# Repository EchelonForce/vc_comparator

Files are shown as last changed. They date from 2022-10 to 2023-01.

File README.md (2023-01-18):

# Eurorack Comparator Module

This is a design for a eurorack comparator module using an LM393.

Full writeup here: https://www.robotdialogs.com/2023/01/eurorack-comparator-module.html

This work is licensed under a Creative Commons Attribution-NonCommercial-ShareAlike 4.0 International License. https://creativecommons.org/licenses/by-nc-sa/4.0/

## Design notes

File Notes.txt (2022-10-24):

https://tinyurl.com/2jhrsgzh
https://tinyurl.com/2guo99mw- updated with output level adjust trim pots
https://tinyurl.com/2kqce7o7 with caps and input filter

Made on bread board, had a few noisy areas but adding caps helped. Also put a rc filter on the signal input in the schematic just in case.

Issues on v1 PCB:
 - Negative of the LM393 should be to GND like on the breadboard... cut the trace to -12V and short C8 to GND with a 0 Ohm.

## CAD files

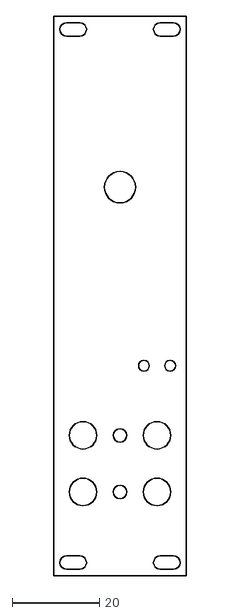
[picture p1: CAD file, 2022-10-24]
front_panel_v1/vc_comparator_v1_front_panel_v1_no_engraving.dxf
30.5 x 128.5

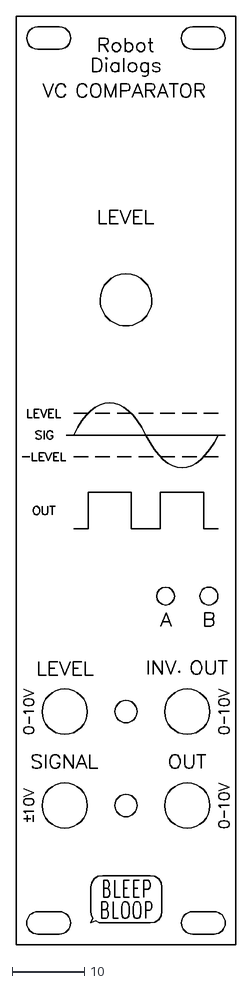
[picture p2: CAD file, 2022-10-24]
front_panel_v1/vc_comparator_v1_front_panel_v1_engraving.dxf
30.4 x 128.4

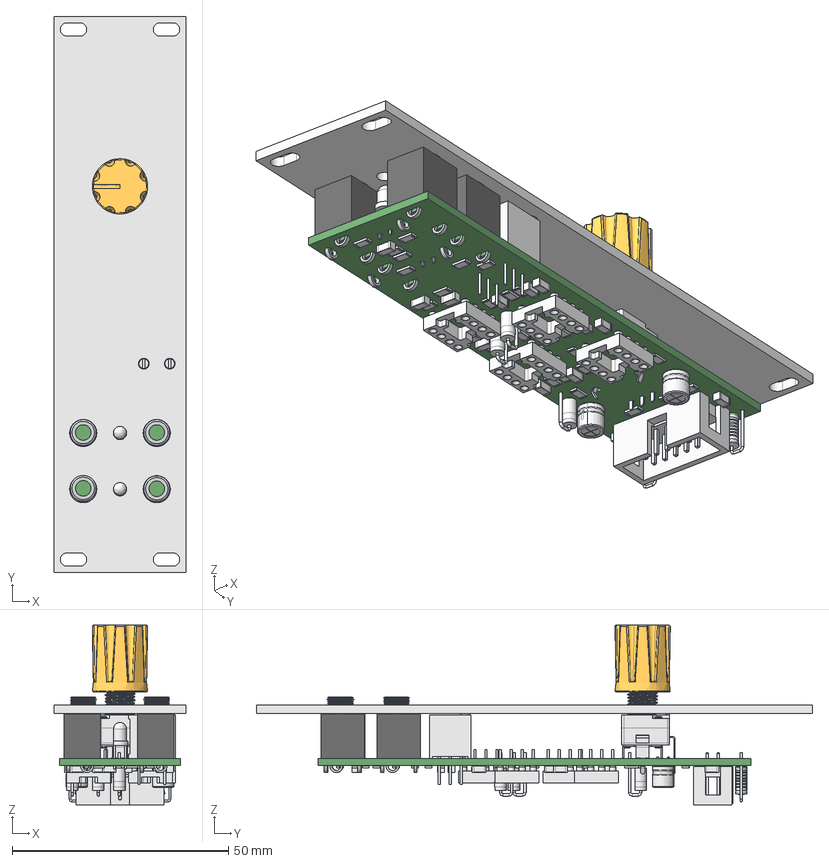
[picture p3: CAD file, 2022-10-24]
front_panel_v1/vc_comparator_v1_front_panel_v1.FCStd
30.5 x 128.5 x 41.6 mm
vc_comparator_v1 PCB

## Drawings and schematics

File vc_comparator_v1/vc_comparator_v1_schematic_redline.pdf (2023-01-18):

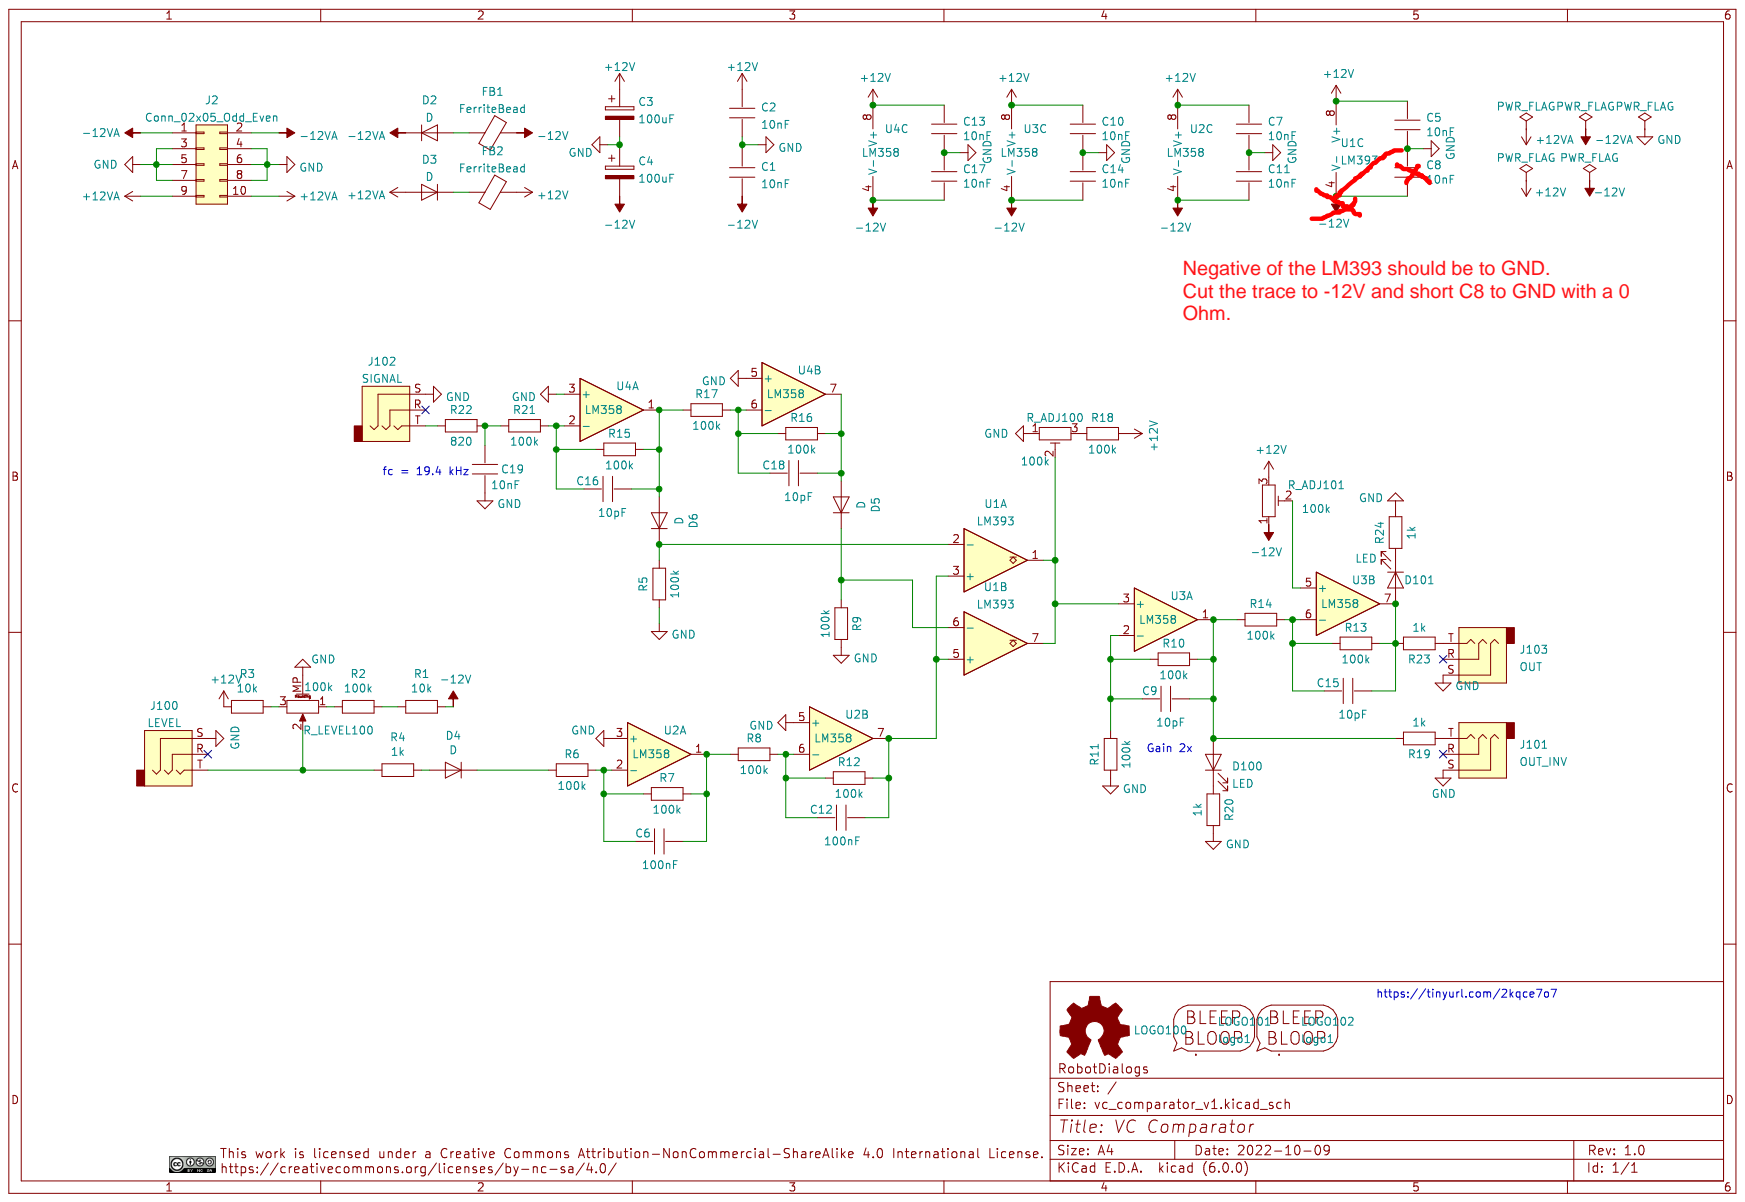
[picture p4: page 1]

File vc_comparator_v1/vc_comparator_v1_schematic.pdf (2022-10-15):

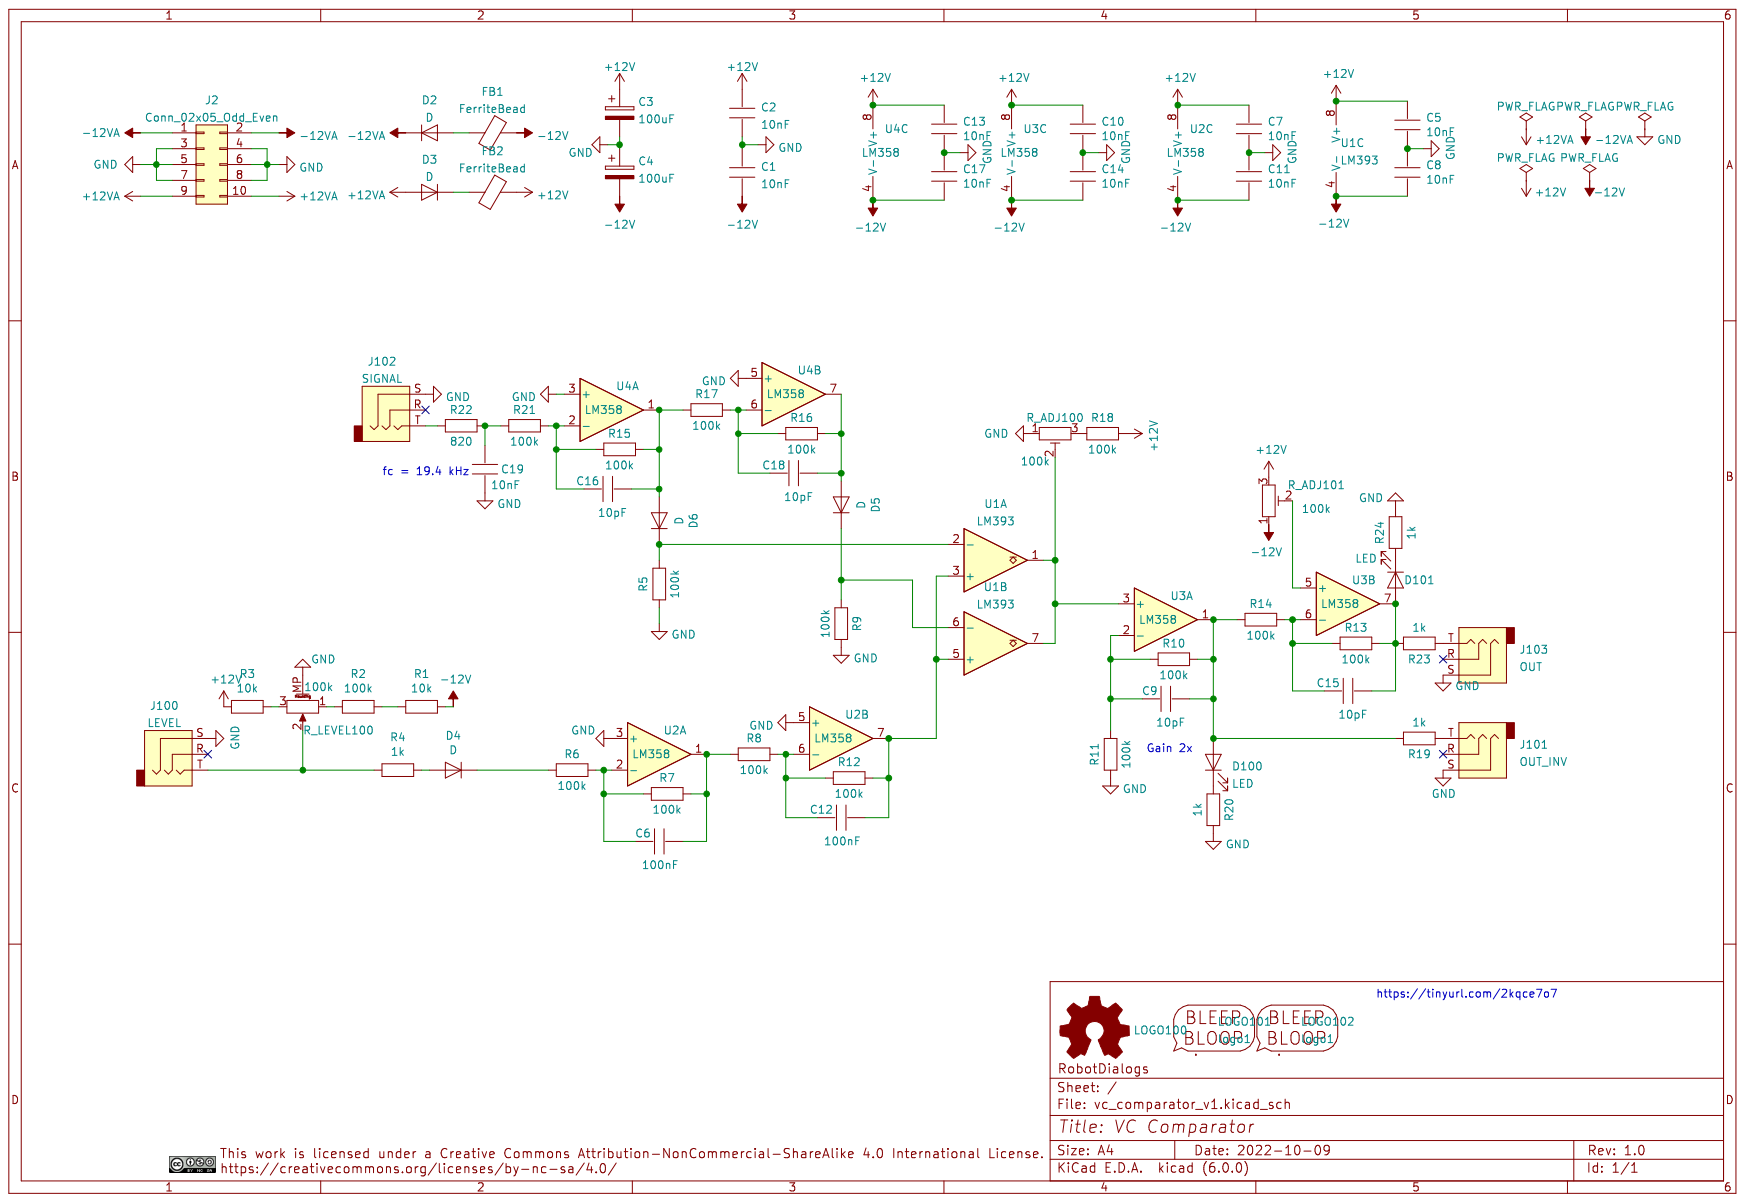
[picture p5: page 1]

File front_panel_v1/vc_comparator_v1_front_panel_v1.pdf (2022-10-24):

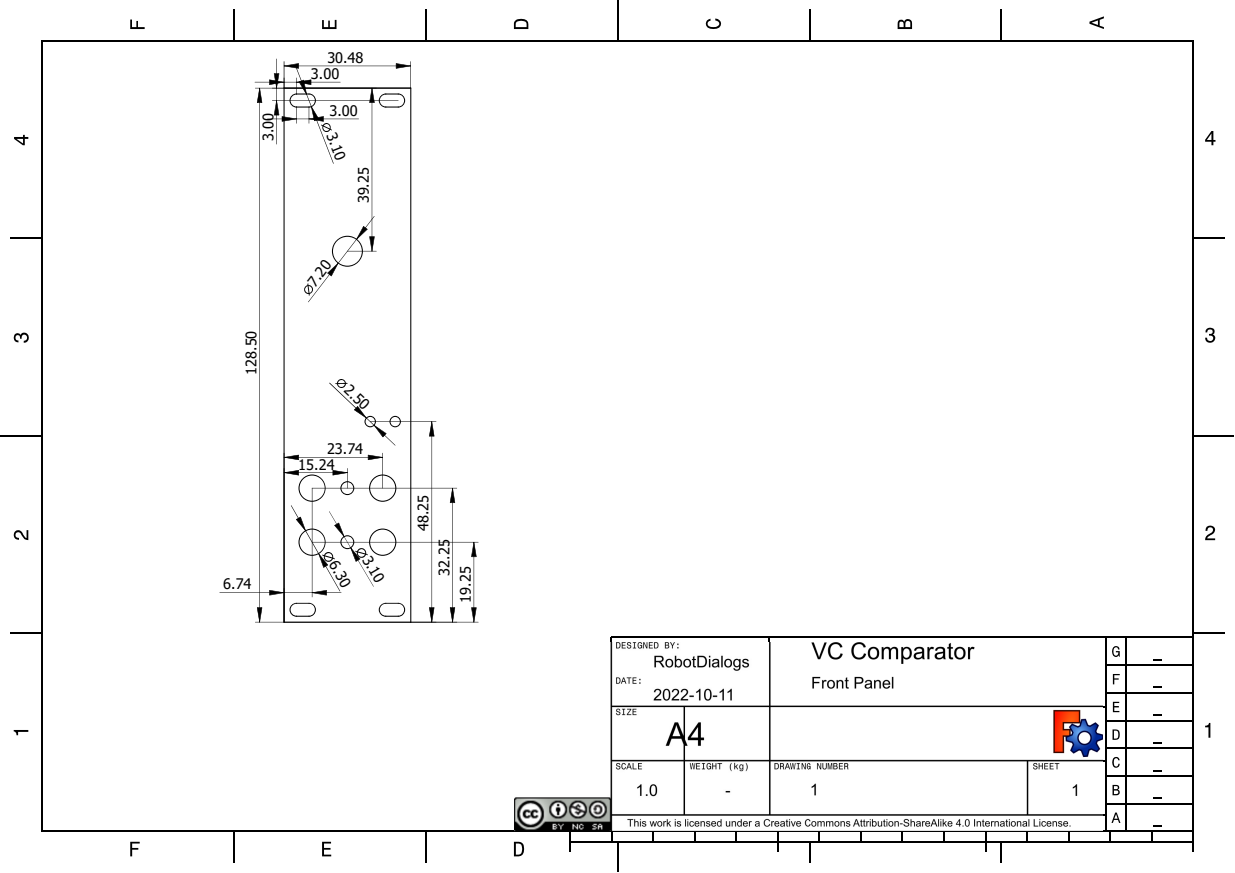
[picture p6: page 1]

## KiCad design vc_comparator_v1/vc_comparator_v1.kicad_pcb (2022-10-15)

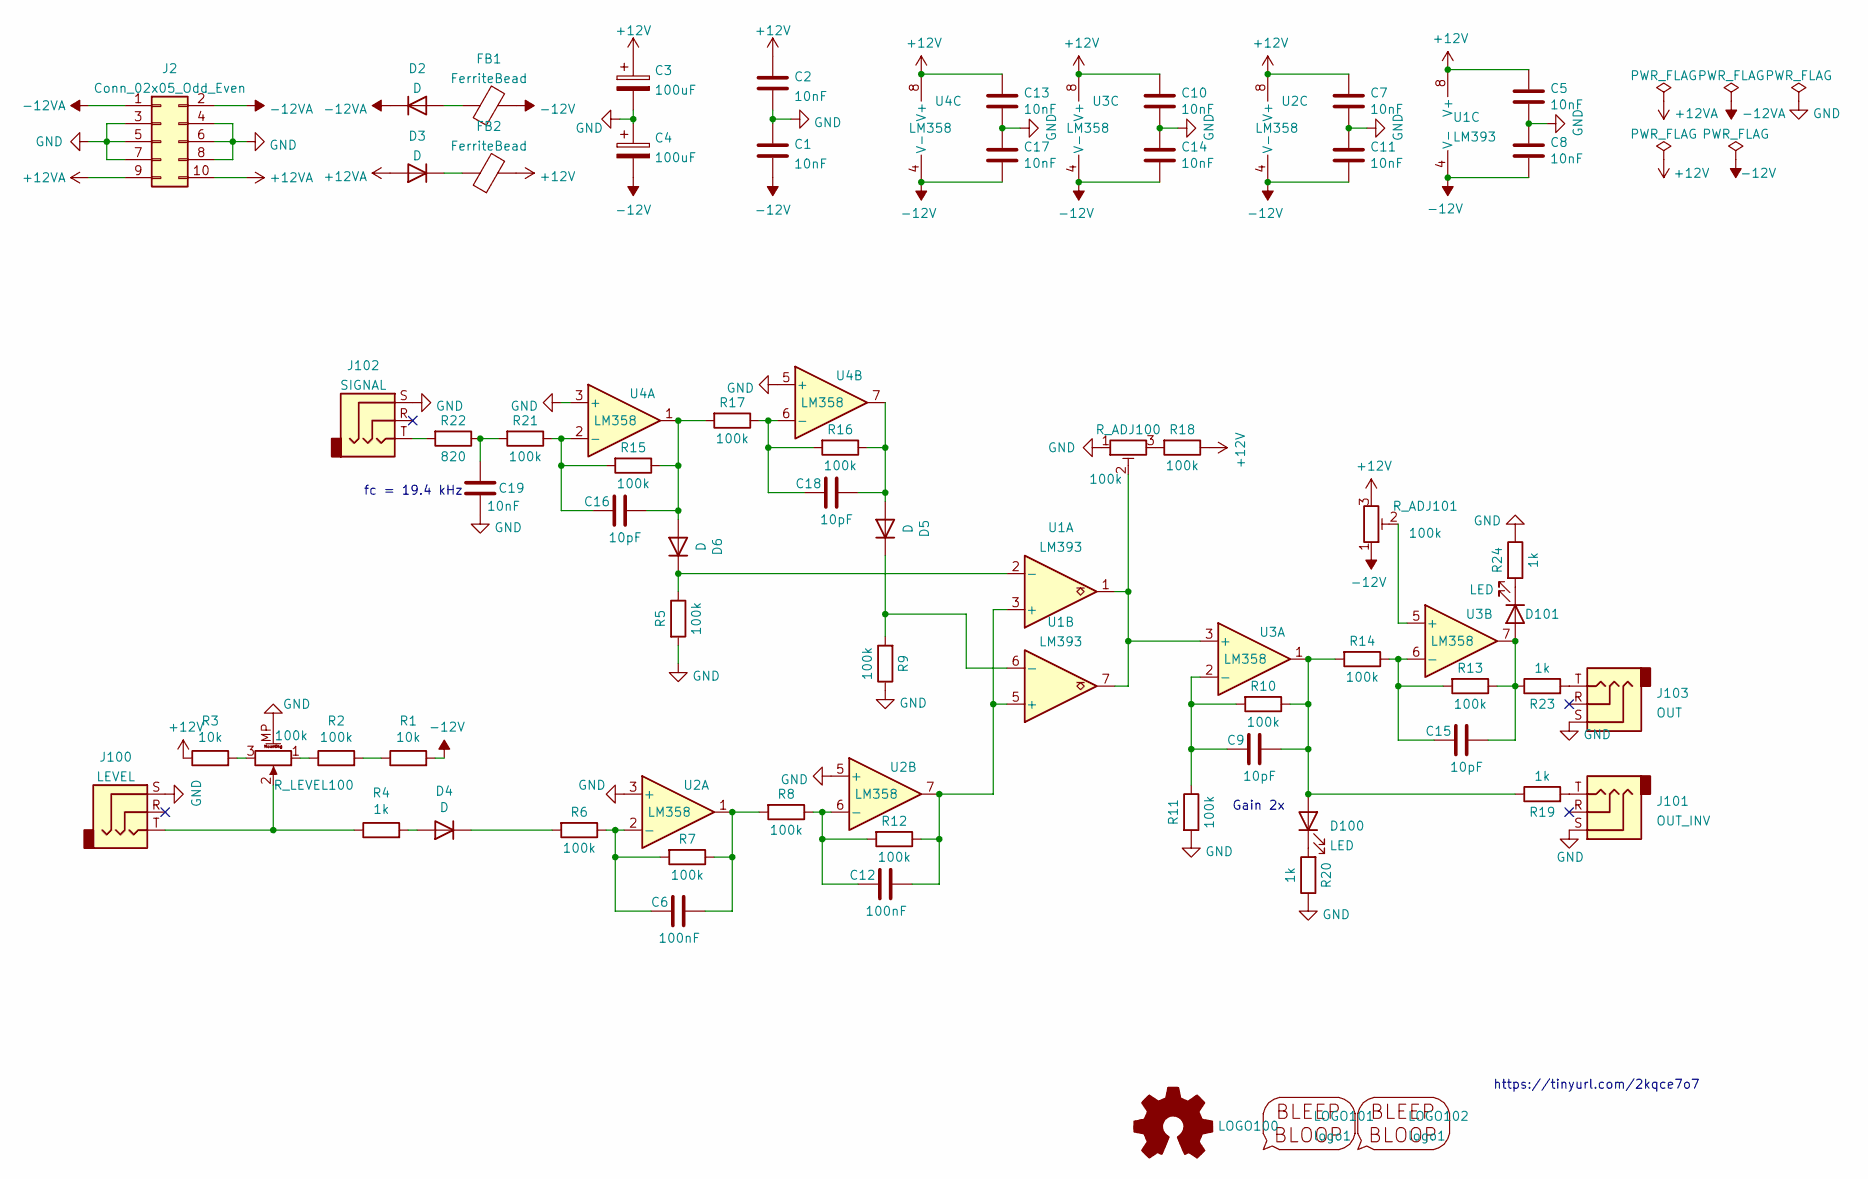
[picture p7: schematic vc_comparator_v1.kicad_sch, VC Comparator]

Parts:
C1, C2, C5, C7, C8, C10, C11, C13, C14, C17, C19: 10nF; C_1206_3216Metric_Pad1.33x1.80mm_HandSolder
C3, C4: 100uF; CP_Radial_D5.0mm_P2.50mm
C6, C12: 100nF; C_1206_3216Metric_Pad1.33x1.80mm_HandSolder
C9, C15, C16, C18: 10pF; C_1206_3216Metric_Pad1.33x1.80mm_HandSolder
D2, D3, D4, D5, D6: D; D_A-405_P2.54mm_Vertical_KathodeUp
D100, D101: LED; LED_D3.0mm
FB1, FB2: FerriteBead; L_Axial_L6.6mm_D2.7mm_P2.54mm_Vertical_Vishay_IM-2
J2: Conn_02x05_Odd_Even; IDC-Header_2x05_P2.54mm_Vertical
J100: LEVEL; Jack_3.5mm_MJ-355W_Vertical
J101: OUT_INV; Jack_3.5mm_MJ-355W_Vertical
J102: SIGNAL; Jack_3.5mm_MJ-355W_Vertical
J103: OUT; Jack_3.5mm_MJ-355W_Vertical
LOGO100: Logo_Open_Hardware_Small; OSHW-Symbol_6.7x6mm_SilkScreen
LOGO101: logo1; Logo1
LOGO102: logo1; Logo2
R1, R3: 10k; R_1206_3216Metric_Pad1.30x1.75mm_HandSolder
R2, R5, R6, R7, R8, R9, R10, R11, R12, R13, R14, R15, R16, R17, R18, R21: 100k; R_1206_3216Metric_Pad1.30x1.75mm_HandSolder
R4, R19, R20, R23, R24: 1k; R_1206_3216Metric_Pad1.30x1.75mm_HandSolder
R22: 820; R_1206_3216Metric_Pad1.30x1.75mm_HandSolder
R_ADJ100, R_ADJ101: 100k; Potentiometer_Bourns_3296W_Vertical
R_LEVEL100: 100k; Potentiometer_Alpha_RD901F-40-00D_Single_Vertical_w_3d
U1: LM393; DIP-8_W7.62mm_Socket_LongPads
U2, U3, U4: LM358; DIP-8_W7.62mm_Socket_LongPads

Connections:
+12V: C2.1, C3.1, C5.2, C7.2, C10.2, C13.2, FB2.2, R3.1, R18.1, R_ADJ101.3, U1.8 (V+), U2.8 (V+), U3.8 (V+), U4.8 (V+)
+12VA: D3.2 (A), J2.9, J2.10
-12V: C1.2, C4.2, C8.1, C11.1, C14.1, C17.1, FB1.2, R1.2, R_ADJ101.1, U1.4 (V-), U2.4 (V-), U3.4 (V-), U4.4 (V-)
-12VA: D2.1 (K), J2.1, J2.2
GND: C1.1, C2.2, C3.2, C4.1, C5.1, C7.1, C8.2, C10.1, C11.2, C13.1, C14.2, C17.2, C19.2, J2.3, J2.4, J2.5, J2.6, J2.7, J2.8, J100.S, J101.S, J102.S, J103.S, R5.2, R9.1, R11.2, R20.1, R24.1, R_ADJ100.1, R_LEVEL100.MP (MountPin), U2.3 (+), U2.5 (+), U4.3 (+), U4.5 (+)
unnamed: C6.1, R7.1, R8.2, U2.1
unnamed: C6.2, R6.1, R7.2, U2.2 (-)
unnamed: C9.1, D100.2 (A), R10.1, R14.2, R19.1, U3.1
unnamed: C9.2, R10.2, R11.1, U3.2 (-)
unnamed: C12.1, R12.1, U1.3 (+), U1.5 (+), U2.7
unnamed: C12.2, R8.1, R12.2, U2.6 (-)
unnamed: C15.1, D101.2 (A), R13.1, R23.1, U3.7
unnamed: C15.2, R13.2, R14.1, U3.6 (-)
unnamed: C16.1, D6.2 (A), R15.1, R17.2, U4.1
unnamed: C16.2, R15.2, R21.1, U4.2 (-)
unnamed: C18.1, D5.2 (A), R16.1, U4.7
unnamed: C18.2, R16.2, R17.1, U4.6 (-)
unnamed: C19.1, R21.2, R22.1
unnamed: D2.2 (A), FB1.1
unnamed: D3.1 (K), FB2.1
unnamed: D4.1 (K), R6.2
unnamed: D4.2 (A), R4.2
unnamed: D5.1 (K), R9.2, U1.6 (-)
unnamed: D6.1 (K), R5.1, U1.2 (-)
unnamed: D100.1 (K), R20.2
unnamed: D101.1 (K), R24.2
unnamed: J100.T, R4.1, R_LEVEL100.2
unnamed: J101.T, R19.2
unnamed: J102.T, R22.2
unnamed: J103.T, R23.2
unnamed: R2.1, R_LEVEL100.1
unnamed: R1.1, R2.2
unnamed: R3.2, R_LEVEL100.3
unnamed: R18.2, R_ADJ100.3
unnamed: R_ADJ100.2, U1.1, U1.7, U3.3 (+)
unnamed: R_ADJ101.2, U3.5 (+)

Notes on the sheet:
fc = 19.4 kHz
Gain 2x
https://tinyurl.com/2kqce7o7

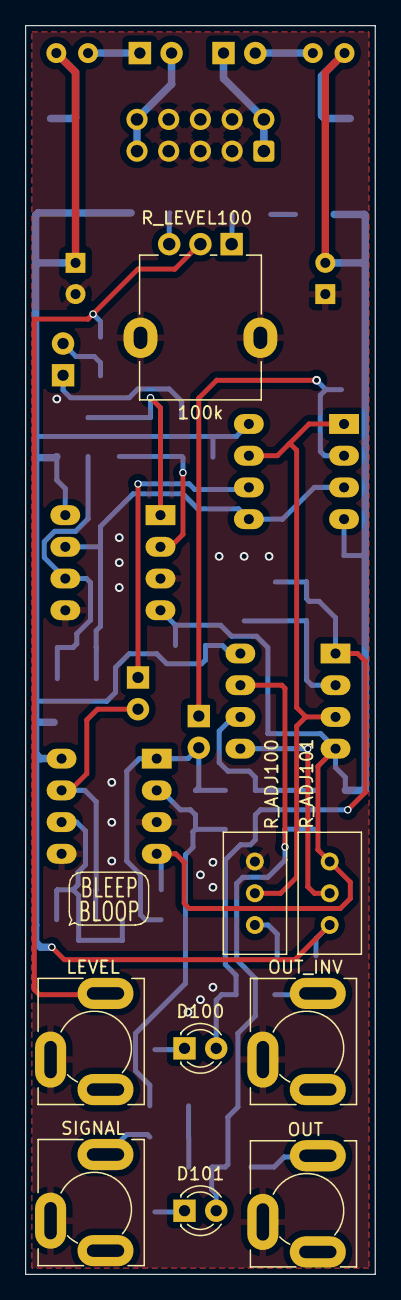
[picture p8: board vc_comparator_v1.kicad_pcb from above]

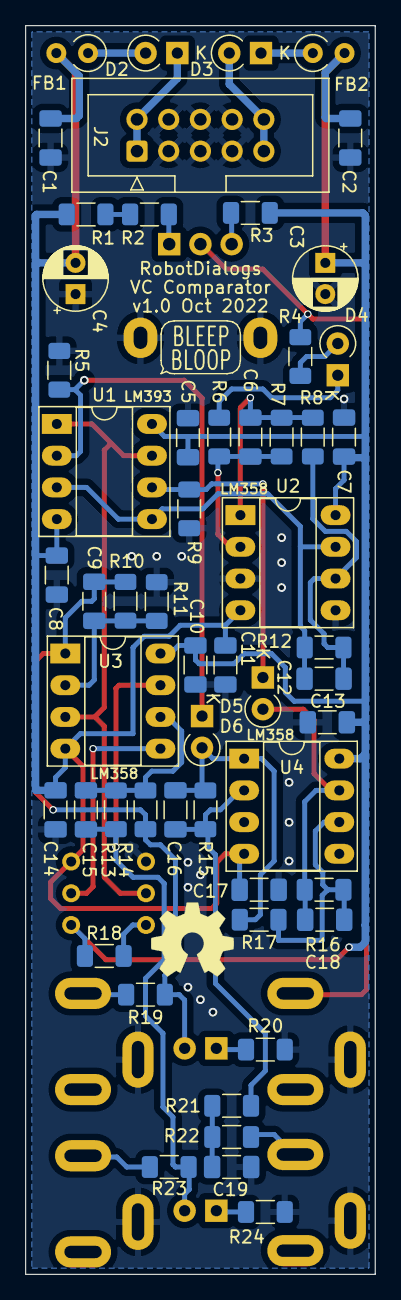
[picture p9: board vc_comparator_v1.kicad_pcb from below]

Board: 2 copper layers, 28.0 x 100.0 mm, 67 parts (56 on the bottom side), 36 nets.

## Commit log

2022-10-09 Schematic and layout draft
    [vc_comparator_v1.kicad_pcb, vc_comparator_v1.kicad_sch]
2022-10-15 Geographic re-annotate and cleanup
    [vc_comparator_v1.kicad_pcb, vc_comparator_v1.kicad_sch]
2022-10-15 Panelized v1
    [vc_comparator_v1_panelized.kicad_pcb]
2022-10-24 Front Panel v1 CAD
    [vc_comparator_v1_front_panel_v1.FCStd, vc_comparator_v1_front_panel_v1_engraving.dxf, vc_comparator_v1_front_panel_v1_no_engraving.dxf]
2023-01-18 Redlined v1 schematic and updates.
